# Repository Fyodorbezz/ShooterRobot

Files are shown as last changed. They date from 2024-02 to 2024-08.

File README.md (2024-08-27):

# Shooter robot
2 Axis gimbling platform with machine vision that recognizes objects on the wall and points laser to them. Created for robotics Olympiad. 

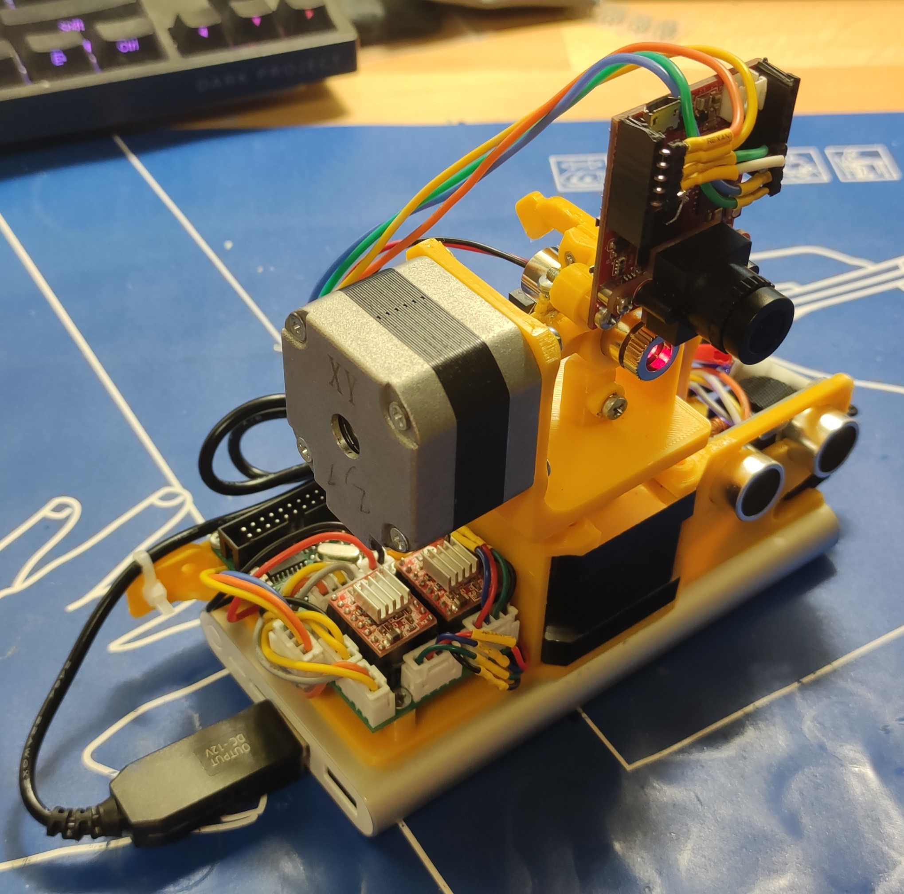
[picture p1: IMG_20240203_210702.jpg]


YouTube link: https://www.youtube.com/watch?v=qjWNKVldk8c

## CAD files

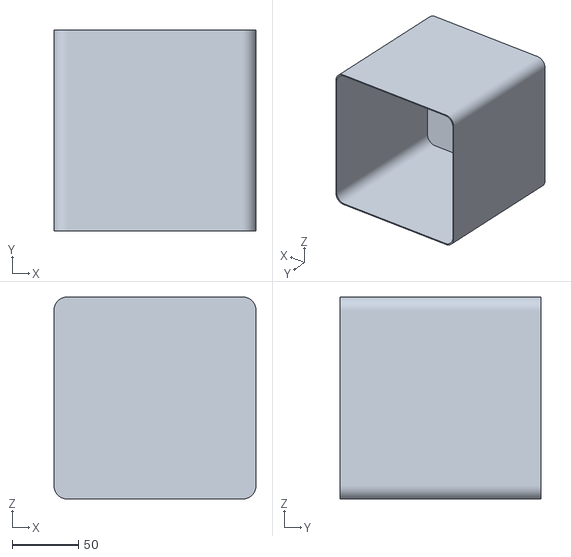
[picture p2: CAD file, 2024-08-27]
3D models/Body1.stl
152.0 x 151.0 x 152.0

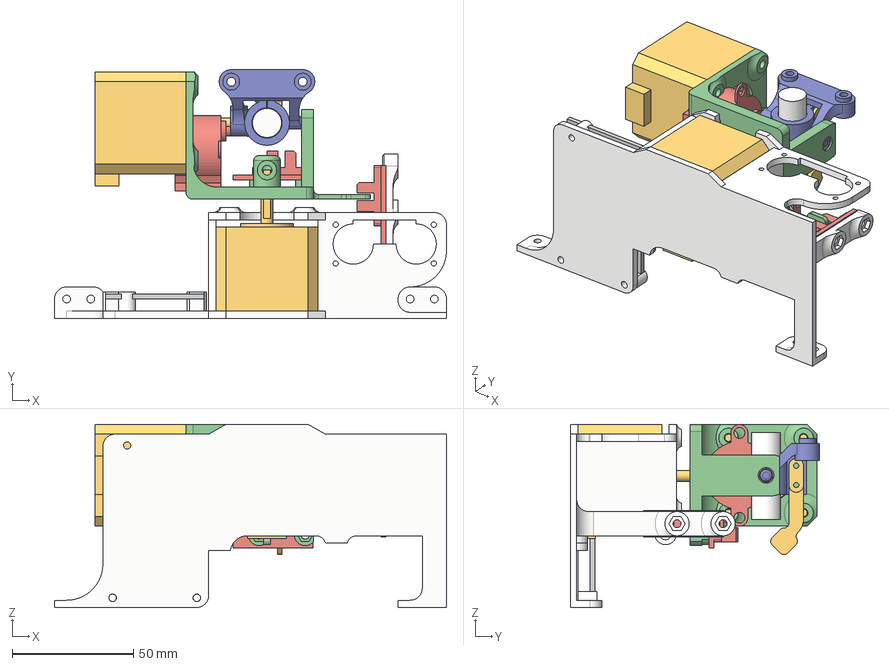
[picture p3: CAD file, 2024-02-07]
3D models/Shooter model.step
161.8 x 102.7 x 75.6 mm
Laser2
Y axis holder
Y axis endstop holder
Laser holder
Small stepper
Nema 17
Y endstop
Baring
X endstop
PCB
Nema 17 (1)

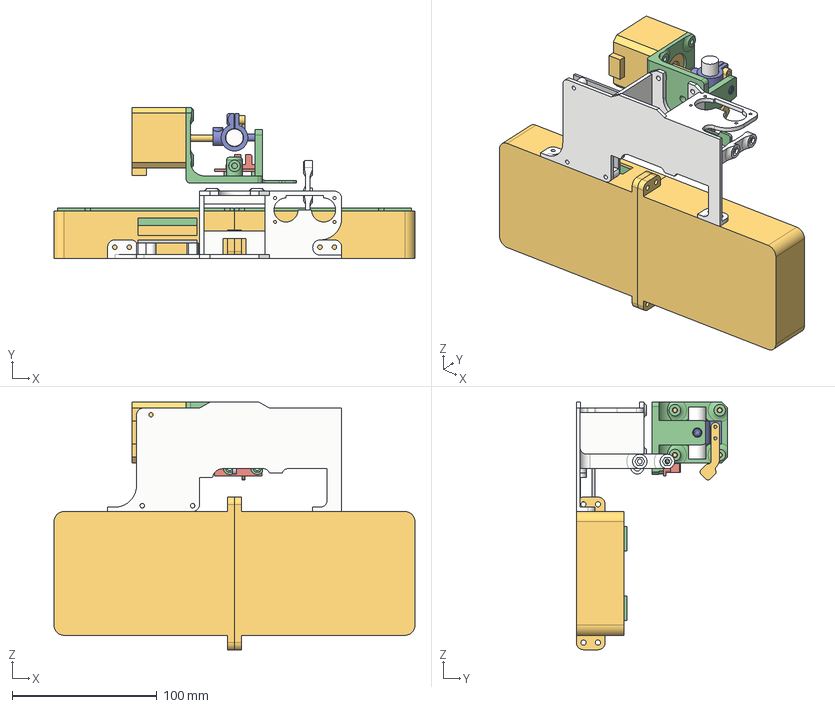
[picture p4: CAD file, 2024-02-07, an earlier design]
3D models/Old_shooter.step
249.6 x 104.7 x 171.2 mm
Laser2
Y axis holder
Y axis endstop holder
Laser holder
Y endstop
Baring
PCB
Nema 17 (1)

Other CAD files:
3D models/Old_shooter.f3d
3D models/Shooter model.f3d

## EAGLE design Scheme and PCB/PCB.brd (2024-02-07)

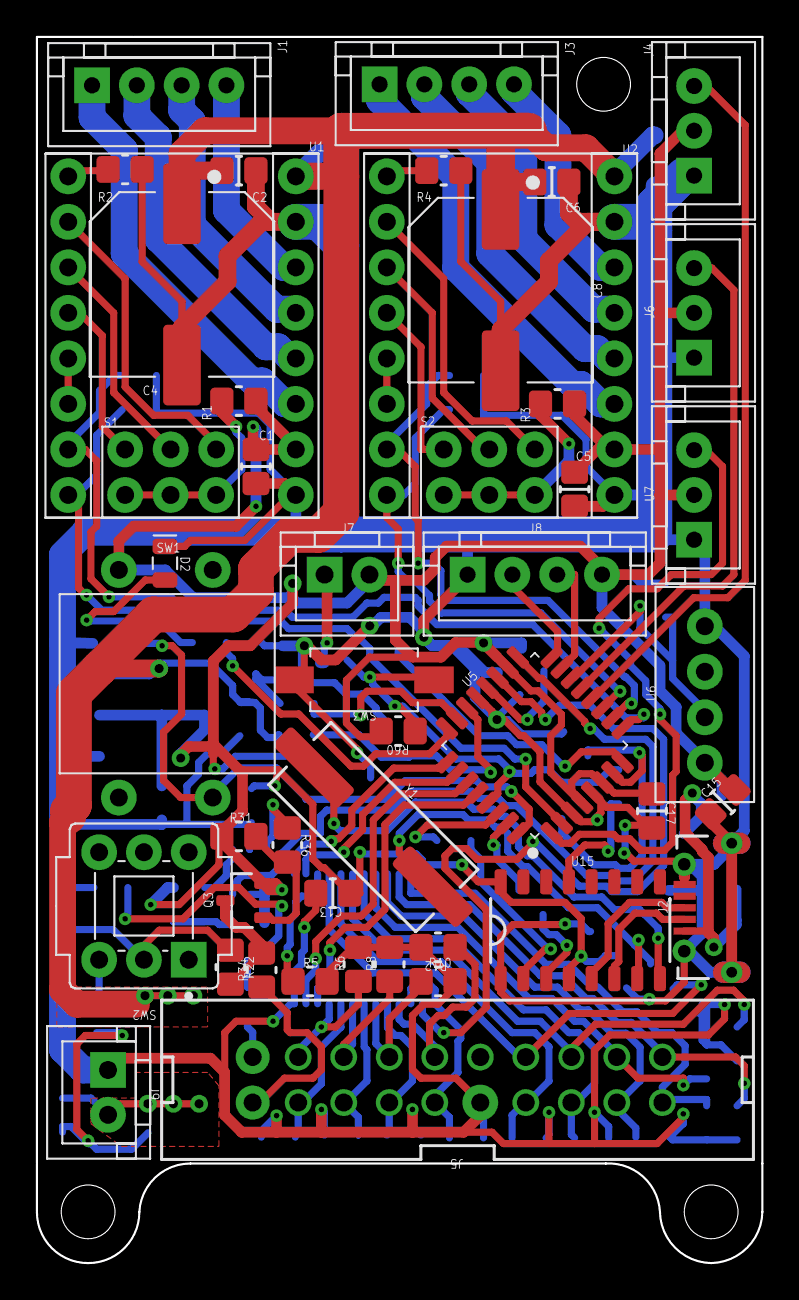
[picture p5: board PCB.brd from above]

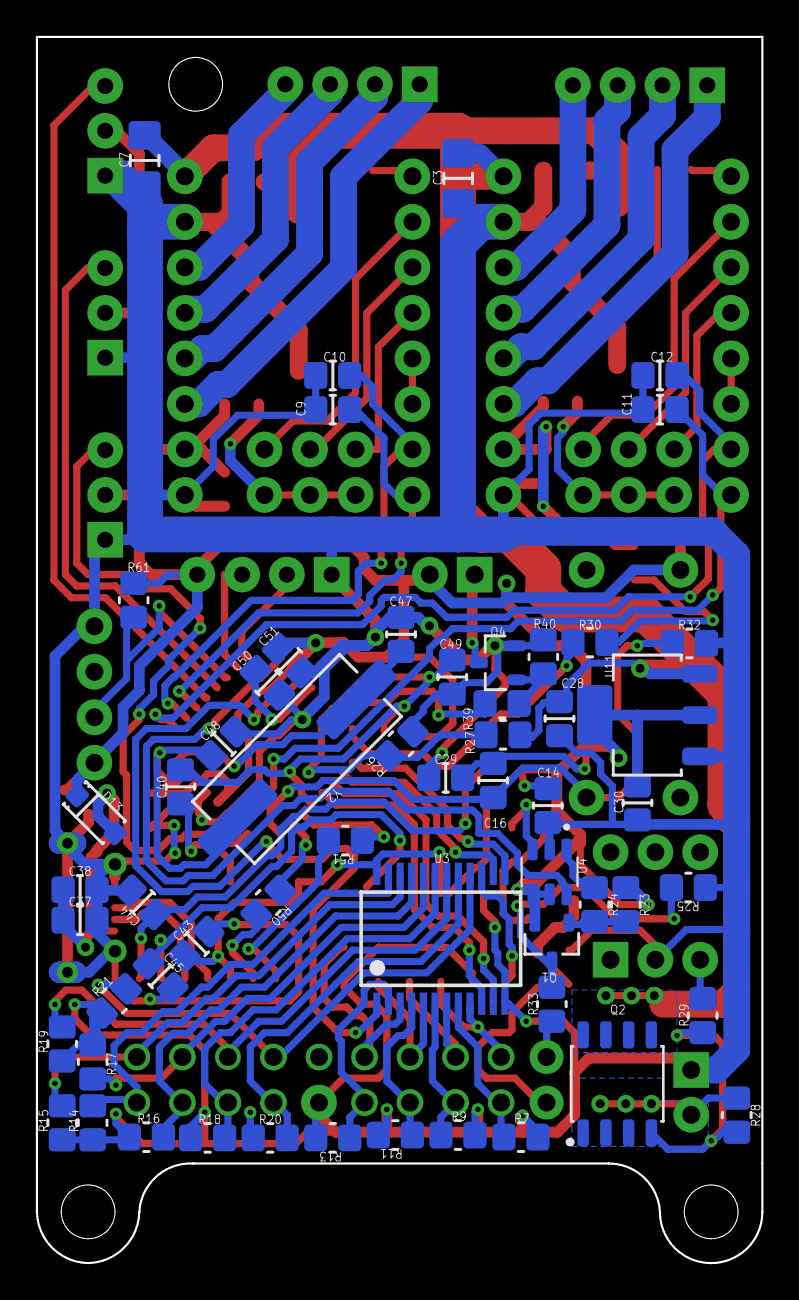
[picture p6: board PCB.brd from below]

Board: 2 copper layers, 40.5 x 68.4 mm, 103 parts (57 on the bottom side), 88 nets.

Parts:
C1, C5: 100nF; Cap
C2, C6: 100nF; Cap_C2
C3, C7: 10uF; CAP_1206
C4: 1000uF; CAPAE-10.3x10.3h13.5
C8: 1000uF; CAPAE-10.3x10.3h13.5_C8
C9, C11, C49: 10nF; Cap_C9
C10, C12: 10nF; Cap_C10
C13, C15, C17: 100nF; Cap_C13
C14: 100nF; Cap_C9
C16: 10nF; Cap_C16
C28: 10uF; Cap_C28
C29: 10uF; Cap_C29
C30: 10uF; Cap_C10
C37, C40, C43: 100nF; Cap_C29
C38: 1uF; Cap_C29
C44, C45, C48: 22pF; Cap_C29
C47: 22pF; Cap_C9
C50, C51: 100nF; Cap_C50
D2: Yellow; LED_0805(2012_Metric)_N_Red
D13: DIO; Diode
J1, J3: STEP_MOT; B4B-XH-A
J2: USB; JEEC_920-E52A2021S10100
J4: ENDSTOP; B3B-XH-A
J5: SENSOR; IDC20M
J6: ENDSTOP; B3B-XH-A_J6
J7: LASER; B2B-XH-A
J8: ULTRASONIC; B4B-XH-A_J8
J9: POWER; B2B-XH-A
Q1: P MOSPFET; SOT23-3P95_230X110L30X43N
Q2: IRF4905LPBF; SOIC8P127_488X585X363L48X40M
Q3: P MOSPFET; SOT23-3P95_230X110L30X43N_Q3
Q4: N MOSPFET; SOT23-3P95_230X110L30X43N_Q4
R1, R3: 1K; Res
R2, R4: 10K; Res_R2
R5, R6, R8, R10, R12, R22, R31, R60: 10K; Res_R5
R7, R9, R11, R13, R14, R15, R16, R17, R18, R19, R20, R21, R23, R25, R28: 10K; Res_R7
R24, R29, R33: 100R; Res_R7
R26, R40: 10K; Res_R26
R27: 8K; Res_R27
R30: 100R; Res_R30
R32: 10K; Res_R30
R34, R36: 100R; Res_R5
R39: 100R; Res_R39
R50, R51: 1K; Res_R7
R61: 47K; Res_R61
S1, S2: 3XSWITCH; Untitled
SW1: ON BUTTN; button
SW2: POWER SWITCH; CK_PVA2-H1
SW3: RES BTN; RES_btn
U1, U2: DRIVER; Untitled_U1
U3: 1:16 MLTIPLECSOR; SSOP24
U4: 1:2 MULTIPLECSOR; SOT95P280X145-6N
U5: ATMEGA328P; QFP32P80_900X900X120L60X37L_AD2
U6: DHT; DHT22
U7: SERVO; B3B-XH-A_J6
U11: AMS1117-3.3; SOT223-4P230_700X180L100X70N_AD1
U15: CH340G; SOIC16P127_1000X600X180L50X45N
Y1: 12MHz; XTAL1140X490X430D1340L450X60N
Y2: 16MHz; XTAL1140X490X430D1340L450X60N_Y2

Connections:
Gnd: C1.2, C2.1, C3.1, C4.2, C5.2, C6.1, C7.1, C8.2, C9.2, C10.2, C11.2, C12.2, C13.2, C14.1, C15.1, C17.2, C28.1, C29.1, C30.2, C37.2, C38.2, C43.2, C44.2, C45.2, C47.2, C48.2, C49.1, C50.2, C51.2, D2.1, J2.5, J2.6@, J2.6@_1, J2.6@_2, J2.6@_3, J4.1, J5.11, J6.1, J8.1, J9.1, Q4.2, R2.1, R4.1, R5.2, R6.2, R7.2, R8.2, R9.2, R10.2, R11.2, R12.2, R13.2, R14.1, R15.1, R16.1, R17.1, R18.1, R19.1, R20.1, R21.1, R22.1, R25.1, R26.1, R32.1, R40.2, SW2.2, SW3.2, U1.9, U1.15, U2.9, U2.15, U3.12, U4.2, U5.3, U5.5, U5.21, U6.4, U7.1, U11.1, U15.1
Net_0: Q4.1, R39.2, R40.1
Net_1: R24.1, U4.1
Net_2: C2.2, C3.2, C4.1, C6.2, C7.2, C8.1, C28.2, Q2.5, Q2.6, Q2.7, Q2.8, R27.1, U1.16, U2.16, U11.3
Net_3: U1.5, U1.6
Net_4: U2.5, U2.6
Net_5: J3.4, U2.14
Net_6: J3.3, U2.13
Net_7: J3.2, U2.12
Net_8: J3.1, U2.11
Net_9: J5.10, R12.1, U3.3
Net_10: J5.2, R33.1
Net_11: Q3.3, R22.2, R34.2
Net_12: R3.2, S2.1, S2.2, S2.3
Net_13: R4.2, U2.1
Net_14: Q3.1, R31.2, R36.2
Net_15: R36.1, U4.3
Net_16: J8.2, U5.16
Net_17: Q1.1, R23.2, R24.2
Net_18: R26.2, R27.2, U5.22
Net_19: J1.4, U1.14
Net_20: J1.3, U1.13
Net_21: J1.2, U1.12
Net_22: J1.1, U1.11
Net_23: S1.6, U1.2
Net_24: S1.5, U1.3
Net_25: S1.4, U1.4
Net_26: R1.2, S1.1, S1.2, S1.3
Net_27: R2.2, U1.1
Net_28: C12.1, U1.7, U5.9
Net_29: C11.1, U1.8, U5.2
Net_30: C10.1, U2.7, U5.10
Net_31: J9.2, Q2.1, Q2.2, Q2.3, R28.1
Net_32: R29.2, SW2.3
Net_33: Q2.4, R28.2, R29.1
Net_36: S2.4, U2.4
Net_37: S2.5, U2.3
Net_38: S2.6, U2.2
Net_41: C9.1, U2.8, U5.11
Net_42: J4.3, U5.12
Net_43: J6.3, U5.13
Net_44: U3.1, U5.19
Net_45: U3.10, U5.28
Net_46: U3.11, U5.27
Net_47: U3.14, U5.26
Net_48: U3.13, U5.25
Net_49: R5.1, U3.15
Net_50: J5.1, R34.1
Net_51: J5.9, R13.1, U3.2
Net_52: Q1.3, R25.2, R33.2
Net_53: J5.7, R11.1, U3.4
Net_54: J5.8, R10.1, U3.5
Net_55: J5.5, R9.1, U3.6
Net_56: J5.6, R8.1, U3.7
Net_57: J5.3, R7.1, U3.8
Net_58: J5.4, R6.1, U3.9
Net_59: J5.19, R14.2, U3.23
Net_60: J5.20, R15.2, U3.22
Net_61: J5.17, R16.2, U3.21
Net_62: J5.18, R17.2, U3.20
Net_63: J5.15, R18.2, U3.19
Net_64: J5.16, R19.2, U3.18
Net_65: J5.13, R20.2, U3.17
Net_66: J5.14, R21.2, U3.16
Net_67: U4.6, U5.17
Net_68: J7.1, Q4.3
Net_69: R50.1, U5.31
Net_70: R39.1, U5.23
Net_72: R51.2, U15.2
Net_73: R50.2, U15.3
Net_74: C40.1, U15.13
Net_75: J8.3, U5.15
Net_76: J2.3, U15.5
Net_77: J2.2, U15.6
Net_78: C37.1, C38.1, D13.2, J2.1
Net_82: R30.2, U5.24
Net_83: D2.2, R30.1
Net_85: C16.2, R32.2, SW1.4, U5.32
Net_86: U5.1, U7.3
Net_87: C40.2, C49.2, R60.1, SW3.1, U5.29
Net_97: C48.1, U5.7, Y2.2
Net_100: C50.1, U5.20
Net_105: R51.1, U5.30
Net_110: C44.1, U15.8, Y1.1
Net_111: C45.1, U15.7, Y1.2
Net_125: R61.2, U5.14, U6.2
Net_155: C47.1, U5.8, Y2.1
USBVCC: C1.1, C5.1, C13.1, C14.2, C15.2, C16.1, C17.1, C29.2, C30.1, C43.1, C51.1, D13.1, J4.2, J6.2, J7.2, J8.4, Q1.2, Q3.2, R1.1, R3.1, R23.1, R31.1, R60.2, R61.1, SW1.1, U1.10, U2.10, U3.24, U4.4, U4.5, U5.4, U5.6, U5.18, U6.1, U7.2, U11.2, U11.4, U15.4, U15.16

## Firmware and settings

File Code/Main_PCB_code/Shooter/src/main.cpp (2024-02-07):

#include <Arduino.h>
#include <GyverStepper.h>
#include <SoftwareSerial.h>


//pins description
#define XSTEP 6
#define XDIR 7
#define XEND 8
#define YSTEP 5
#define YDIR 4
#define YEND 9

#define TRIG 11
#define ECHO 12

#define LASER A0

#define DHT 10

#define CAM_TX 13
#define CAM_RX 3

#define BTN 2
#define LED A1
#define BAT_VOL A7

GStepper<STEPPER2WIRE> stepper_x(3200, XSTEP, XDIR); 
GStepper<STEPPER2WIRE> stepper_y(3200, YSTEP, YDIR); 

SoftwareSerial camera(CAM_RX, CAM_TX);


int distance_to_wall = 0;
int distance_to_wall_2 = 0;
int trget_coordinates[9][2];

int cur_target = 0;
bool next_target = 1;

bool move_ended=0;

unsigned long long debounce_timer = 0;
 
void check_voltage(){
  //chack woltage to avoid damge to acumulator
  if (analogRead(BAT_VOL)/110.0 < 7.2){
    digitalWrite(LED, 1); 
    while(1){
      delay(1000);
    }
  }
  Serial.println(analogRead(BAT_VOL)/110.0);
}

void measure_distance(){
  //function to ,easure distance multiple time and get filtered result
  float distance_sum=0;
  for(int i=0; i<100; i++){
    digitalWrite(TRIG, HIGH);
    delayMicroseconds(10);
    digitalWrite(TRIG, LOW);

    int tmp = 0;
    tmp = pulseIn(ECHO, HIGH);
    Serial.println(tmp);
    distance_sum += tmp*0.17;
  }
  distance_to_wall_2 = int(distance_sum/100.0+0.5);
}

void home(){
  //function that homes axes and set them to sero
  stepper_x.setRunMode(KEEP_SPEED);
  stepper_y.setRunMode(KEEP_SPEED);
  stepper_x.setSpeed(-200);
  while(!digitalRead(XEND)){
    stepper_x.tick();
  }
  stepper_x.setSpeed(0);

  stepper_y.setSpeed(-200);
  while(!digitalRead(YEND)){
    stepper_y.tick();
  }
  stepper_y.setSpeed(0);

  stepper_x.reset();
  stepper_y.reset();

  stepper_x.setRunMode(FOLLOW_POS);
  stepper_y.setRunMode(FOLLOW_POS);
  stepper_x.setTargetDeg(-5.8);
  stepper_y.setTargetDeg(31);
  while(stepper_x.getState()||stepper_y.getState()){
    stepper_x.tick();
    stepper_y.tick();
  }
  stepper_x.reset();
  stepper_y.reset();
  //digitalWrite(LASER, 1);
}

void button_pressed(){
  //button pressed interrupt
  if(millis() - debounce_timer > 1000){
    next_target = 1;
    debounce_timer = millis();
  }
}

int sign(int a){
  if(a==0){
    return 0;
  }
  if (a>0){
    return 1;
  }
  return -1;
}


void setup() {
  Serial.begin(9600);
  camera.begin(9600);

  //setup all pins
  pinMode(LED, OUTPUT);

  pinMode(XSTEP, OUTPUT);
  pinMode(XDIR, OUTPUT);
  pinMode(YSTEP, OUTPUT);
  pinMode(YDIR, OUTPUT);

  pinMode(LASER, OUTPUT);

  pinMode(TRIG, OUTPUT);

  //set motor parameters
  stepper_x.setMaxSpeedDeg(100);
  stepper_y.setMaxSpeedDeg(100);
  stepper_x.setAccelerationDeg(50);
  stepper_y.setAccelerationDeg(50);
  stepper_y.reverse(1);

  attachInterrupt(0, button_pressed, RISING);

  //check_voltage();
  home();
  if(digitalRead(BTN) == 1){
    //debug mode: turn on laser and measure distance constantly
    digitalWrite(LASER, 1);
    while(1){
      digitalWrite(TRIG, HIGH);
      delayMicroseconds(10);
      digitalWrite(TRIG, LOW);

      int tmp = 0;
      tmp = pulseIn(ECHO, HIGH);
      Serial.println(tmp*0.17);
    }
  }

  measure_distance();

  //correction for sensor angle and distance between sensor and camera
  distance_to_wall_2=int(distance_to_wall_2*0.944+0.5+15.4);
  distance_to_wall_2 -=40;

  //tilt camera if to close to wall
  if(distance_to_wall_2 < 1300){
    stepper_y.setTargetDeg(-21.2);
    while(stepper_y.getState()){
      stepper_y.tick();
    }
  }
  Serial.println(distance_to_wall_2);

  //send distance to camera
  int distance_tmp = 0;
  if(distance_to_wall_2<1024){
    distance_tmp = distance_to_wall_2*6;
  }
  else{
    distance_tmp = distance_to_wall_2;
  }
  Serial.println(distance_tmp);
  Serial.println(distance_to_wall_2);
  camera.write(distance_tmp & 0x00FF);
  camera.write((distance_tmp >> 8) & 0x00FF);
  byte buff = 0;
  int pointer = 0;
  bool point_comp=0;
  //recieve points coordinaes from camera
  while (1){
    if (camera.available()){
      buff = camera.read(); 
      if (buff == 'e'){
        break;
      }
      trget_coordinates[pointer/2][pointer%2] = buff - 3;
      //mirror points if needed
      /*if(pointer%2 == 1){
        if(trget_coordinates[pointer/2][0] <= 0){
          trget_coordinates[pointer/2+1][0]= -1*trget_coordinates[pointer/2][0];
          trget_coordinates[pointer/2+1][1]= -1*trget_coordinates[pointer/2][1];
        }
        else{
          trget_coordinates[pointer/2+1][0]= trget_coordinates[pointer/2][0];
          trget_coordinates[pointer/2+1][1]= trget_coordinates[pointer/2][1];
          trget_coordinates[pointer/2][0] = -1*trget_coordinates[pointer/2][0];
          trget_coordinates[pointer/2][1] = -1*trget_coordinates[pointer/2][1];
        }
        pointer +=2;
      }*/
      pointer ++;
      
    }
  }
  //add cental point if needed
  //trget_coordinates[4][0] = 0;
  //trget_coordinates[4][1] = ;
  Serial.println(distance_to_wall_2);
  distance_to_wall_2+=40;
}

void loop() {
  if (next_target){
    Serial.println(distance_to_wall_2);

    Serial.println(100*sign(trget_coordinates[cur_target][0]) + 200*(trget_coordinates[cur_target][0]-1*sign(trget_coordinates[cur_target][0])));

    //convert target coordinates into stepper angles
    stepper_x.setTargetDeg(-degrees(atan2((100*sign(trget_coordinates[cur_target][0]) + 200*(trget_coordinates[cur_target][0]-1*sign(trget_coordinates[cur_target][0]))), distance_to_wall_2 )));
    if(trget_coordinates[cur_target][1]==0){
      stepper_y.setTargetDeg(-degrees(atan2(300 - 15, pow(pow(distance_to_wall_2, 2) + pow((100*sign(trget_coordinates[cur_target][0]) + 200*(trget_coordinates[cur_target][0]-1*sign(trget_coordinates[cur_target][0]))), 2), 0.5))));
    }
    else{
      if(trget_coordinates[cur_target][1] < 0){
        trget_coordinates[cur_target][1]++;
      }
      stepper_y.setTargetDeg(-degrees(atan2((200*(4-(trget_coordinates[cur_target][1]+2))) - 15, pow(pow(distance_to_wall_2, 2) + pow((100*sign(trget_coordinates[cur_target][0]) + 200*(trget_coordinates[cur_target][0]-1*sign(trget_coordinates[cur_target][0]))), 2), 0.5))));
    }
    
    Serial.println(trget_coordinates[cur_target][0]-1*sign(trget_coordinates[cur_target][0]));
    Serial.println(trget_coordinates[cur_target][1]+3); 
    next_target = 0;
    move_ended = 0;
    cur_target ++;
    
    camera.write(10);
    delay(1000);
    digitalWrite(LASER, 0);
    digitalWrite(LED, 0); 
  }
  stepper_x.tick();
  stepper_y.tick();
  if(stepper_x.getState() == 0 && stepper_y.getState() == 0 && !move_ended){
    //when steppers finished moving turn on led's
    camera.write(20);
    digitalWrite(LASER, 1);
    digitalWrite(LED, 1);
    move_ended = 1;
  }
  delay(1);
}

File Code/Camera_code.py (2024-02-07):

# Untitled - By: Пользователь - Сб янв 13 2024

import sensor, image, time
import pyb
from pyb import UART
from struct import *


uart = UART(1, 9600, timeout_char=9)

red_led = pyb.LED(1)
blue_led = pyb.LED(3)

sensor.reset()
sensor.set_pixformat(sensor.RGB565)
sensor.set_framesize(sensor.VGA)
sensor.set_vflip(True)
sensor.set_hmirror(True)
sensor.skip_frames(time = 2000)

cross_cor = [0, 0]
#red = [(20, 34, 21, 48, 4, 42)]
#red = [(14, 29, 29, 43, 16, 29)]
#red = [(18, 43, 17, 44, 5, 39)]
red = [(23, 49, 22, 47, 8, 38)]
#cross color mask

circles_cor = []
#blue = (20, 38, -15, 4, -35, -8)
#blue = (8, 28, -6, 9, -25, -1)
#blue=(7, 39, -2, 13, -57, -6)
blue=(7, 36, -3, 20, -43, -11)
#targets color mask

clock = time.clock()

coef = 4
coef2 = 3.545
distance = 0

crit_distance = 1300

TARGET_POINTS = [(106,   94),   # (x, y) CHANGE ME!
                 (508, 102),   # (x, y) CHANGE ME!
                 (575, 385), # (x, y) CHANGE ME!
                 (29,   391)]

#points for perspective correction when we tikt camera

def find_center():
    #function for finding central cross
    global cross_cor

    count = 0
    for j in range(50):
        if distance<crit_distance:
            img = sensor.snapshot().lens_corr(strength = 2.5, zoom = 0.7)
            img = img.rotation_corr(corners = TARGET_POINTS)
        else:
            img = sensor.snapshot().lens_corr(strength = 2.5, zoom = 0.8)

        cross = img.find_blobs(red)
        r = cross[0]
        if r.pixels() > 50:
            cross_cor[0] += r.cx()
            cross_cor[1] += r.cy()
            count += 1
    cross_cor[0] /= count
    cross_cor[1] /= count

def find_targets():
    #function that finds targets
    global circles_cor

    for i in range(50):
        if distance<crit_distance:
            img = sensor.snapshot().lens_corr(strength = 2.5, zoom = 0.7)
            img = img.rotation_corr(corners = TARGET_POINTS)
        else:
            img = sensor.snapshot().lens_corr(strength = 2.5, zoom = 0.8)

        img.binary([blue])
        img.to_grayscale()
        img.erode(1, 8)
        img.dilate(2)
        circles = img.find_blobs([(128,256)])
        tmp = []
        for i in circles:
            if(abs(round(i.x()+i.w()/2) - cross_cor[0]) * coef < 600 and abs(round(i.y()+i.h()/2) - cross_cor[1]) * coef < 400):
                tmp.append([round(i.x()+i.w()/2), round(i.y()+i.h()/2)])
        circles_cor.append(tmp)
    tmp = []
    for i in circles_cor:
        for j in i:
            flag = 0
            if len(tmp) > 0:
                for k in tmp:
                    if (abs(k[0][0] - j[0]) <= 5 and abs(k[0][1] - j[1]) <= 5):
                        k[1] += 1
                        flag = 1
            if flag == 0:
                tmp.append([j, 1])
    circles_cor = []
    for i in tmp:
        if i[1] > 30:
            circles_cor.append(i[0])
    print(circles_cor)
    for i in range(len(circles_cor)):
        tmp = ((circles_cor[i][0] - cross_cor[0]) * coef)/200.0
        tmp = int(tmp+1*sign(tmp))
        circles_cor[i].insert(0, tmp)
        tmp = ((circles_cor[i][2] - cross_cor[1]) * coef)/200.0
        tmp = int(tmp+1*sign(tmp))
        circles_cor[i].insert(1, tmp)
        circles_cor[i].insert(0, (circles_cor[i][0]**2 + circles_cor[i][1]**2)**0.5)


def sign(a):
    if a>0:
        return 1
    return -1



def get_distance():
    #function that recieves distance from main pcb
    global coef, distance
    while uart.any() < 2:
        pass
    tmp = uart.read()
    distancee = unpack('h', tmp)
    distance = distancee[0]
    print(distance)
    if distance > 4000:
        distance = round(distance/6)
    print(distance)
    if distance < crit_distance:
        coef = coef2
    coef *= distance/1370
    print(distance)

trash = uart.read()
get_distance()
'''while(True):
    clock.tick()
    if distance<crit_distance:
        img = sensor.snapshot().lens_corr(strength = 2.5, zoom = 0.7)
        img = img.rotation_corr(corners = TARGET_POINTS)
    else:
        img = sensor.snapshot().lens_corr(strength = 2.5, zoom = 0.8)
'''



find_center()
find_targets()

#filter target and send them to main pcb
circles_cor.sort()
for i in circles_cor:
    print(i)
    b = [i[1] + 3, i[2] + 3]
    print(bytearray(b))
    uart.write(bytearray(b))
uart.write('e')

while(True):
    clock.tick()
    #turn led on and of when main PCB order
    if uart.any():
        print('sdada')
        tmp = uart.read()
        tmp2 = unpack('B', tmp)[0]
        print(tmp2)
        if tmp2 == 20:
            red_led.on()
            blue_led.on()
        if tmp2 == 10:
            red_led.off()
            blue_led.off()

    '''if distance<crit_distance:
        img = sensor.snapshot().lens_corr(strength = 2.5, zoom = 0.7)
        img = img.rotation_corr(corners = TARGET_POINTS)
    else:
        img = sensor.snapshot().lens_corr(strength = 2.5, zoom = 0.8)

    img.draw_cross(int(cross_cor[0]), int(cross_cor[1]), (128, 0, 255), 5)
    for i in range(len(circles_cor)):
        img.draw_circle(circles_cor[i][3], circles_cor[i][4], 2, (255, 20, 0))
    #print(clock.fps())'''

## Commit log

2024-02-07 Add scheme and pcb
2024-02-07 Add all matereals
    [Old_shooter.f3d, Old_shooter.step, Shooter model.f3d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]
2024-02-07 Add PCB and scheme with different format
    [PCB.brd, Scheme.sch]
2024-08-27 Added preview
    [Body1.stl]
